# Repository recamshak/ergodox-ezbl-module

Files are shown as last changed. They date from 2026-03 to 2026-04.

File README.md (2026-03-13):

# ErgoDox EZBL

A drop-in board for the ErgoDox EZ keyboard, using a Nice!Nano V2 running [ZMK](https://zmk.dev), giving you Bluetooth connectivity without any modifications to the case.

## Features

- Drop-in replacement for the original ErgoDox EZ PCB, no modifications to the case needed
- Bluetooth wireless via Nice!Nano V2
- [ZMK Studio](https://zmk.studio) support for real-time keymap editing

## Usage

Add this module to your ZMK config's `west.yml`:

```yaml
manifest:
  remotes:
    - name: ergodox-ezbl
      url-base: https://github.com/recamshak/ergodox-ezbl-module
  projects:
    - name: zmk
      remote: ergodox-ezbl
      revision: main
      import: app/west.yml
  self:
    path: config
```

Then reference the `ergodox_ezbl_left` and `ergodox_ezbl_right` shields in your build configuration.

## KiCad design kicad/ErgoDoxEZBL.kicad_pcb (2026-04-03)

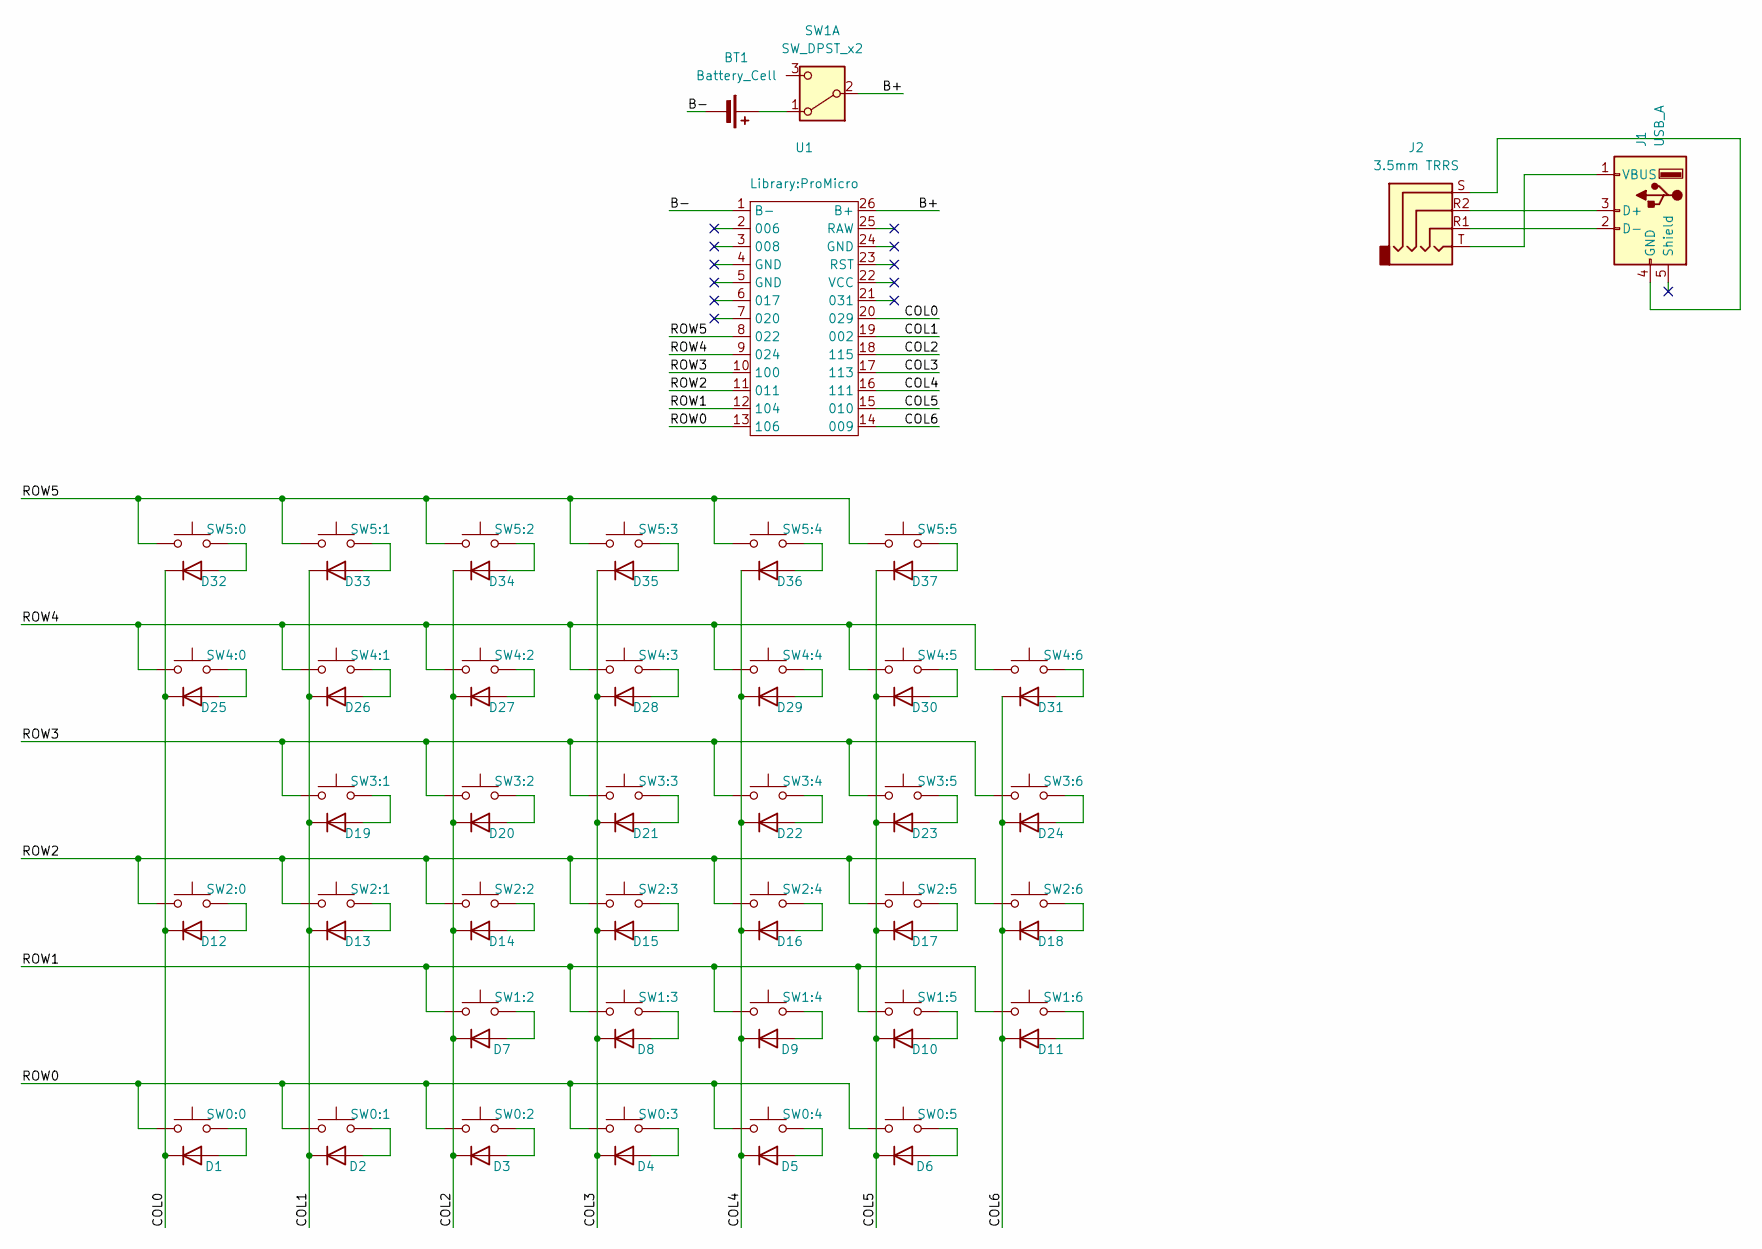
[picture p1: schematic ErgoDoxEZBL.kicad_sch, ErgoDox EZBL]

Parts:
BT1: Battery_Cell; SolderWire-0.1sqmm_1x02_P3.6mm_D0.4mm_OD1mm
D1, D2, D3, D4, D5, D6, D7, D8, D9, D10, D11, D12, D13, D14, D15, D16, D17, D18, D19, D20, D21, D22, D23, D24, D25, D26, D27, D28, D29, D30, D31, D32, D33, D34, D35, D36, D37: 1N4148; D_DO-35_SOD27_P7.62mm_Horizontal
J1: USB_A; SolderWire-0.1sqmm_1x04_P3.6mm_D0.4mm_OD1mm
J2: 3.5mm TRRS; SJ3-35094A
SW0:0, SW0:1, SW0:2, SW0:3, SW0:4, SW0:5, SW1:2, SW1:3, SW1:4, SW1:5, SW1:6, SW2:0, SW2:1, SW2:2, SW2:3, SW2:4, SW2:5, SW2:6, SW3:1, SW3:2, SW3:3, SW3:4, SW3:5, SW3:6, SW4:0, SW4:1, SW4:2, SW4:3, SW4:4, SW4:5, SW4:6, SW5:0, SW5:1, SW5:2, SW5:3, SW5:4, SW5:5: SW_Push; SW_Hotswap_Kailh_MX_1.00u
SW1: SW_DPST_x2; Power switch
U1: ProMicro

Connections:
/B+: SW1.2 (B), U1.26 (B+)
/B-: BT1.2 (-), U1.1 (B-)
/COL0: D1.1 (K), D12.1 (K), D25.1 (K), D32.1 (K), U1.20 (029)
/COL1: D2.1 (K), D13.1 (K), D19.1 (K), D26.1 (K), D33.1 (K), U1.19 (002)
/COL2: D3.1 (K), D7.1 (K), D14.1 (K), D20.1 (K), D27.1 (K), D34.1 (K), U1.18 (115)
/COL3: D4.1 (K), D8.1 (K), D15.1 (K), D21.1 (K), D28.1 (K), D35.1 (K), U1.17 (113)
/COL4: D5.1 (K), D9.1 (K), D16.1 (K), D22.1 (K), D29.1 (K), D36.1 (K), U1.16 (111)
/COL5: D6.1 (K), D10.1 (K), D17.1 (K), D23.1 (K), D30.1 (K), D37.1 (K), U1.15 (010)
/COL6: D11.1 (K), D18.1 (K), D24.1 (K), D31.1 (K), U1.14 (009)
/ROW0: SW0:0.1, SW0:1.1, SW0:2.1, SW0:3.1, SW0:4.1, SW0:5.1, U1.13 (106)
/ROW1: SW1:2.1, SW1:3.1, SW1:4.1, SW1:5.1, SW1:6.1, U1.12 (104)
/ROW2: SW2:0.1, SW2:1.1, SW2:2.1, SW2:3.1, SW2:4.1, SW2:5.1, SW2:6.1, U1.11
/ROW3: SW3:1.1, SW3:2.1, SW3:3.1, SW3:4.1, SW3:5.1, SW3:6.1, U1.10 (100)
/ROW4: SW4:0.1, SW4:1.1, SW4:2.1, SW4:3.1, SW4:4.1, SW4:5.1, SW4:6.1, U1.9 (024)
/ROW5: SW5:0.1, SW5:1.1, SW5:2.1, SW5:3.1, SW5:4.1, SW5:5.1, U1.8 (022)
unnamed: BT1.1 (+), SW1.1 (A)
unnamed: D1.2 (A), SW0:0.2
unnamed: D2.2 (A), SW0:1.2
unnamed: D3.2 (A), SW0:2.2
unnamed: D4.2 (A), SW0:3.2
unnamed: D5.2 (A), SW0:4.2
unnamed: D6.2 (A), SW0:5.2
unnamed: D7.2 (A), SW1:2.2
unnamed: D8.2 (A), SW1:3.2
unnamed: D9.2 (A), SW1:4.2
unnamed: D10.2 (A), SW1:5.2
unnamed: D11.2 (A), SW1:6.2
unnamed: D12.2 (A), SW2:0.2
unnamed: D13.2 (A), SW2:1.2
unnamed: D14.2 (A), SW2:2.2
unnamed: D15.2 (A), SW2:3.2
unnamed: D16.2 (A), SW2:4.2
unnamed: D17.2 (A), SW2:5.2
unnamed: D18.2 (A), SW2:6.2
unnamed: D19.2 (A), SW3:1.2
unnamed: D20.2 (A), SW3:2.2
unnamed: D21.2 (A), SW3:3.2
unnamed: D22.2 (A), SW3:4.2
unnamed: D23.2 (A), SW3:5.2
unnamed: D24.2 (A), SW3:6.2
unnamed: D25.2 (A), SW4:0.2
unnamed: D26.2 (A), SW4:1.2
unnamed: D27.2 (A), SW4:2.2
unnamed: D28.2 (A), SW4:3.2
unnamed: D29.2 (A), SW4:4.2
unnamed: D30.2 (A), SW4:5.2
unnamed: D31.2 (A), SW4:6.2
unnamed: D32.2 (A), SW5:0.2
unnamed: D33.2 (A), SW5:1.2
unnamed: D34.2 (A), SW5:2.2
unnamed: D35.2 (A), SW5:3.2
unnamed: D36.2 (A), SW5:4.2
unnamed: D37.2 (A), SW5:5.2
unnamed: J1.3 (D+), J2.R2
unnamed: J1.2 (D-), J2.R1
unnamed: J1.4 (GND), J2.S
unnamed: J1.1 (VBUS), J2.T

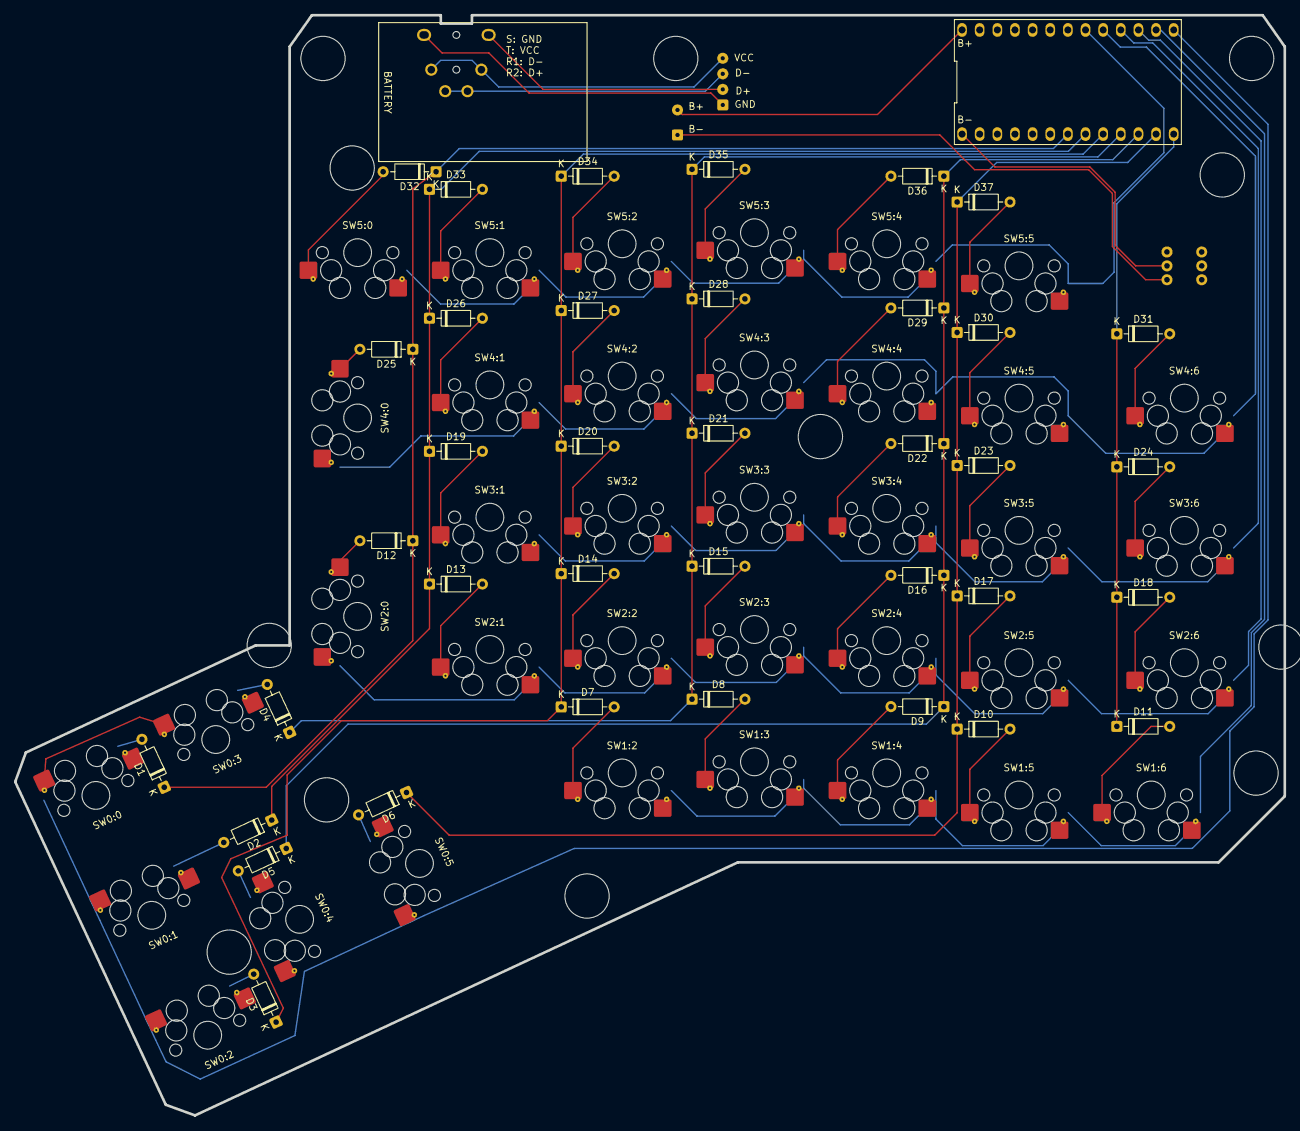
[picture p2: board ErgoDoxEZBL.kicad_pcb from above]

Board: 2 copper layers, 182.8 x 158.4 mm, 79 parts (1 on the bottom side), 57 nets.

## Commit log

2026-03-03 Add schematics & PCB
    [ErgoDoxEZBL.kicad_pcb, ErgoDoxEZBL.kicad_sch]
2026-03-03 Fix DC Jack footprint
2026-03-03 Fix MCU position
    [ErgoDoxEZBL.kicad_pcb]
2026-03-13 PCB v2
    - Fix DC jack footprint
    - Single reversible PCB for both split
    [ErgoDoxEZBL-B_Cu.gbr, ErgoDoxEZBL-B_Mask.gbr, ErgoDoxEZBL-B_Paste.gbr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]
2026-03-24 Enable peripheral battery level report
2026-04-03 USB connection via TRRS jack connector
    [ErgoDoxEZBL-B_Cu.gbr, ErgoDoxEZBL-B_Mask.gbr, ErgoDoxEZBL-B_Paste.gbr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]
